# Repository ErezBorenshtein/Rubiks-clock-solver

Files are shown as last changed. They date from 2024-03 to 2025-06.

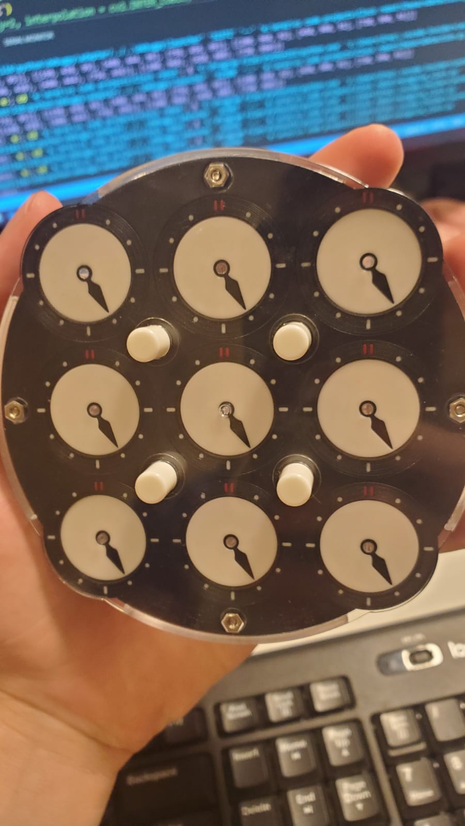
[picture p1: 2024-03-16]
Code/python_code/clock_imgs/Clock-photo3.jpg

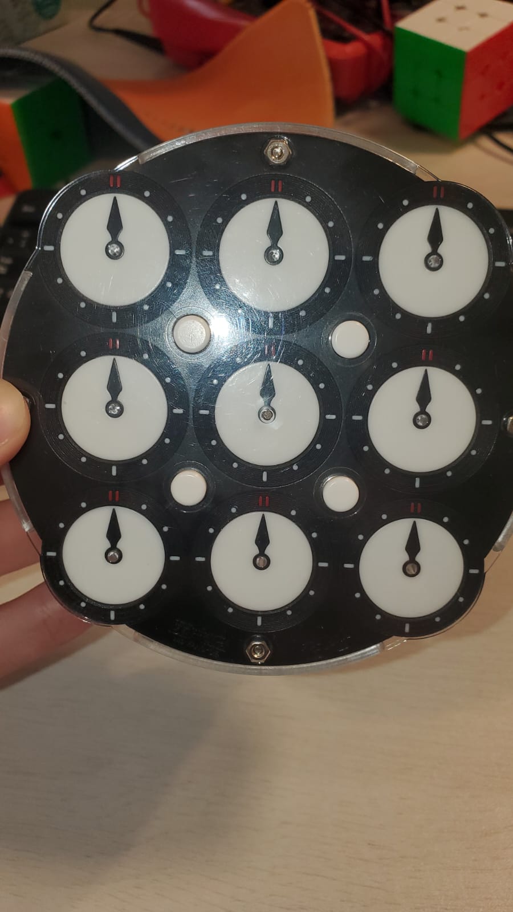
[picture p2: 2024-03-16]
Code/python_code/clock_imgs/Clock-photo.jpg

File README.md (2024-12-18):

# Rubik's Clock Solver Robot

## Overview
The robot was meticulously designed and programmed to solve the Rubik's Clock puzzle in record time, showcasing precision engineering and advanced programming techniques.

## Features
- **Precision Mechanisms:** Powered by Nema 17 Bipolar 0.9° stepper motors for high accuracy.
- **Solving Algorithm:** Optimized algorithm for determining the quickest solution.
- **Hardware Components:**
  - Arduino Mega for robot control
  - Teensy 4.1 for LED display management
  - JF-0530B solenoids for precise movement
  - 4TB-8800TB motor driver
  - 32x64 LED display for status updates
- **Autonomous Operation:** Fully automated solving process from start to finish, not including clock's recognition.

## Hardware Setup
1. **Motors:** Connect the Nema 17 stepper motors to the motor driver.
2. **Solenoids:** Interface the JF-0530B solenoids with the Arduino Mega.
3. **Microcontrollers:**
   - Use the Arduino Mega as the main controller for the robot.
   - Use the Teensy 4.1 to control the 32x64 LED screen.
4. **LED Screen:** Mount the screen to display solving steps and timings.
5. **Power Supply:** Ensure stable power for all components.

### Dependencies
- [Arduino IDE](https://www.arduino.cc/en/software)
- [Teensyduino](https://www.pjrc.com/teensy/teensyduino.html)

### Installation
1. Clone the repository:
   ```bash
   git clone https://https://github.com/ErezBorenshtein/Rubiks-clock-solver.git
   ```
2. Open the Arduino IDE and load the provided `.ino` files for the Arduino Mega and Teensy 4.1.
3. Install the required libraries via the Arduino Library Manager, and add the Teensy board from the Board Manager.
4. Upload the respective code to the Arduino Mega and Teensy 4.1.
5. Install the necessary libraries for the clock recognition system.

### Execution
1. Power on the robot.
2. Place the scrambled Rubik's Clock on the designated platform.
3. Press the start button to initiate the solving process.
4. Monitor the progress on the LED display.

## Challenges
- Designing precise mechanisms to manipulate the clock's dials and clocks.
- Synchronizing multiple components, including motors, solenoids, and the LED display.
- Creating full simulation of the clock using to test the algorithm. 
- Creating full 3D model of the robot to test the mechanism. 

## License
This project is open-sourced under the MIT License. Feel free to use, modify, and distribute as per the terms of the license.

## Acknowledgments
- The speedcubing community for inspiration.
- Open-source libraries and tools that made this project possible.
- Nyanyan-Maker for the inspiration and for suggesting motors and drivers. [youtube](https://www.youtube.com/watch?v=jc3e5xadDao)

## Contact
For questions or collaborations, reach out via [email](erez.borenshtein@gmail.com).

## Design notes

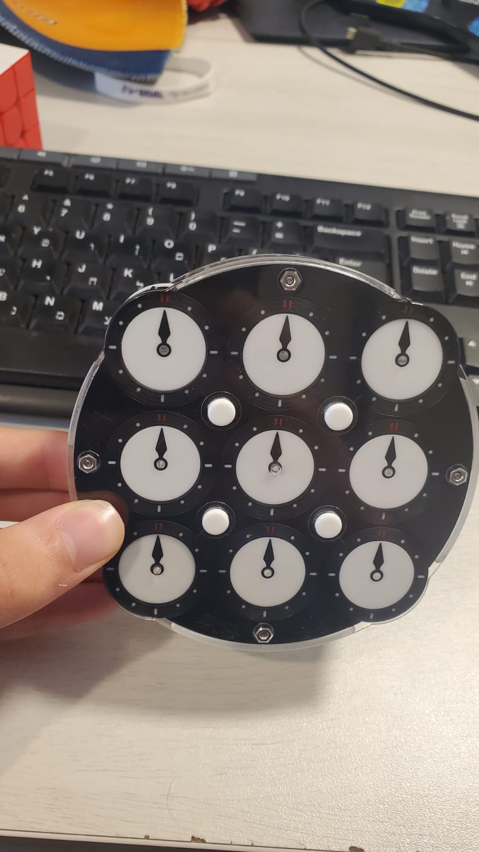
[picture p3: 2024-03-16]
Code/python_code/clock_imgs/Clock-photo2.jpg

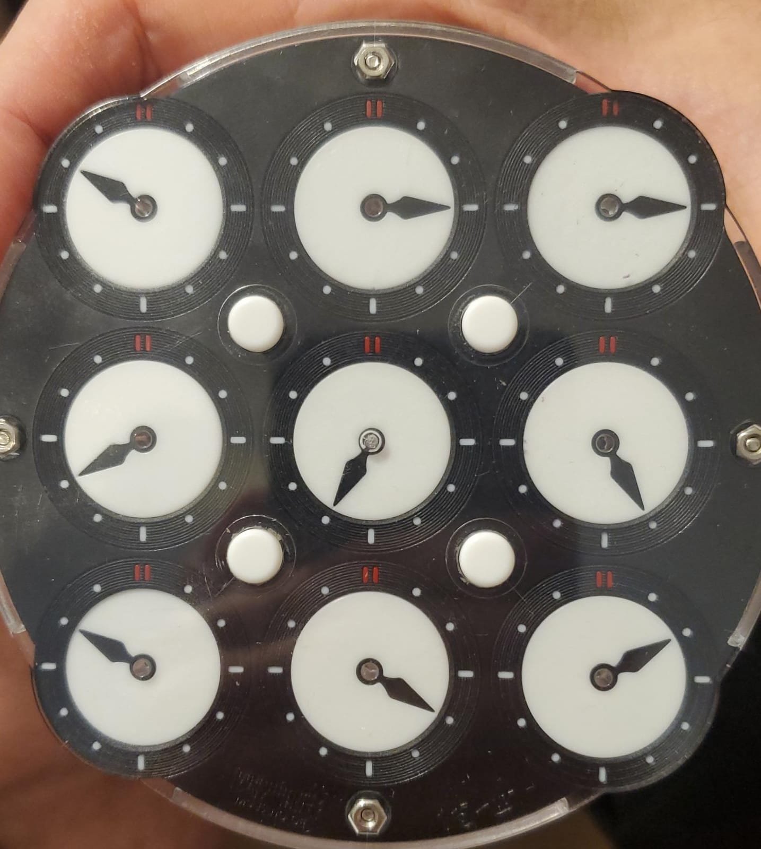
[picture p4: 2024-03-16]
Code/python_code/clock_imgs/Clock-photo6.jpg

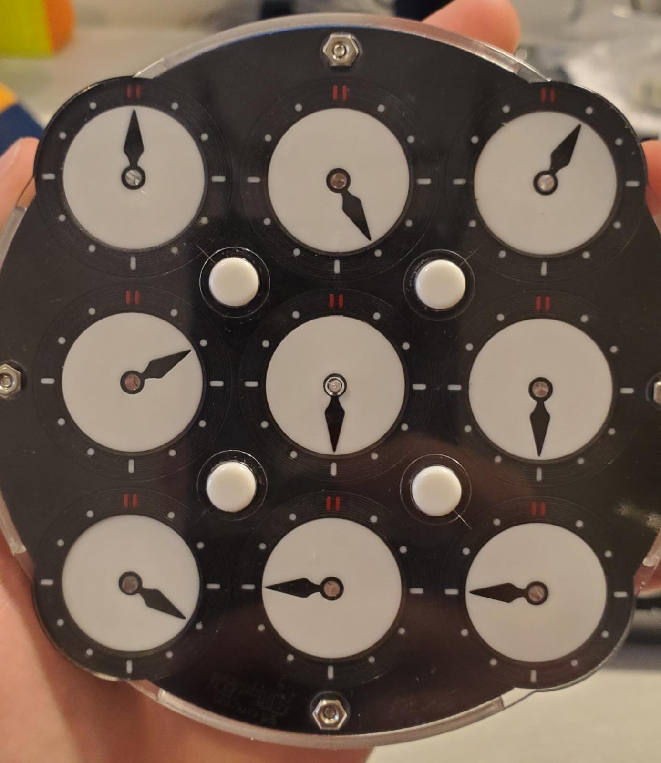
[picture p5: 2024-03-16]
Code/python_code/clock_imgs/Clock-photo5.jpg

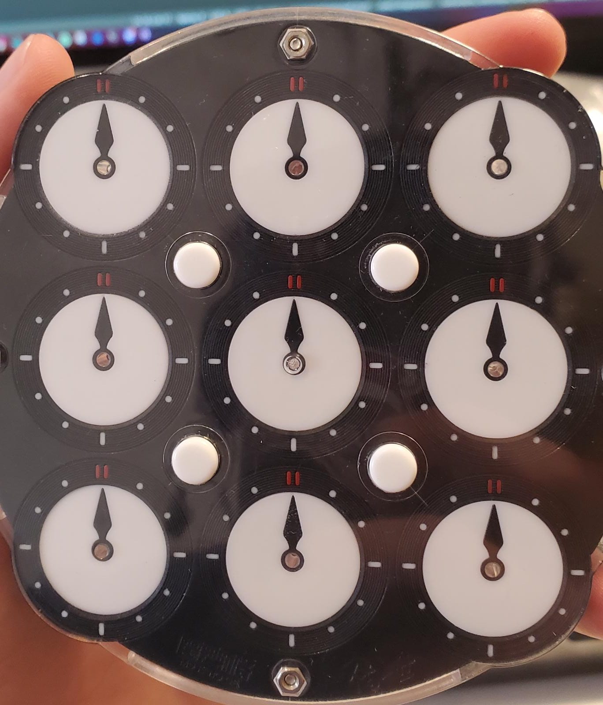
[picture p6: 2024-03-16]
Code/python_code/clock_imgs/Clock-photo4.jpg

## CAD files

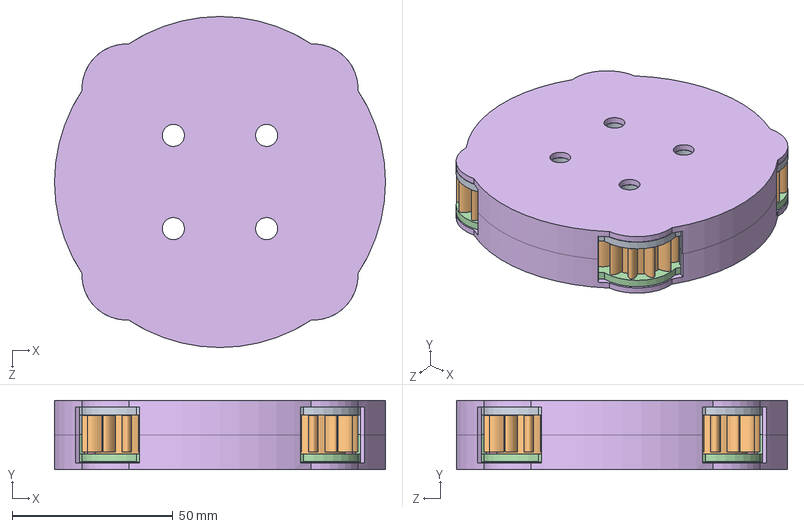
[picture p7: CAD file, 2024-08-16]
Solid parts/clock_model/full clock.SLDASM
103.0 x 21.5 x 103.0 mm
cover_white
corner_wheel x 4
black_edge x 5
cover_black
white_edge x 5
transparent_layer x 2

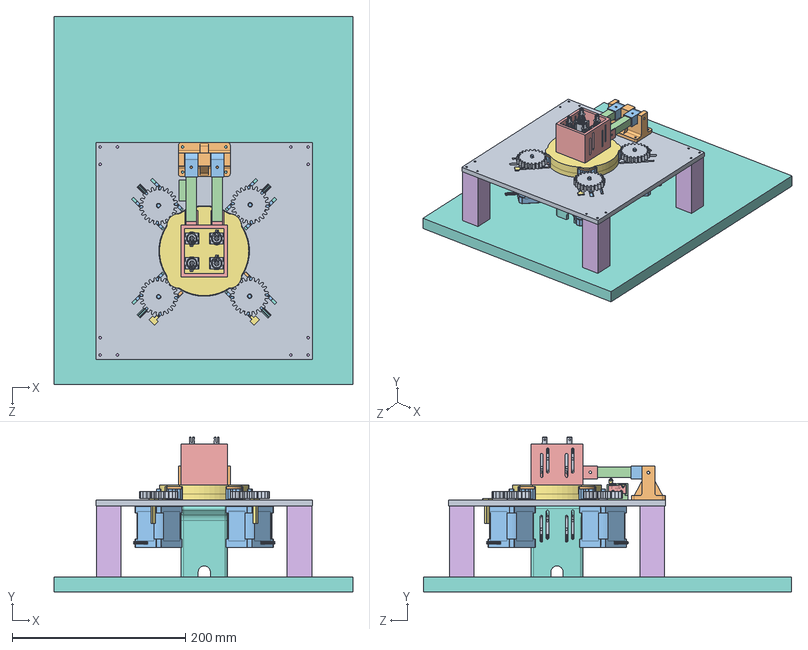
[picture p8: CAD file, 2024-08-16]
Solid parts/full machine.SLDASM
345.0 x 178.6 x 425.0 mm
Base
cover_white
corner_wheel x 4
black_edge x 5
cover_black
white_edge x 5
transparent_layer x 2
solenoid_mount.SLDASM
User Library-JF-0520B x 8
bridge base
brige_part_2 x 2
stick x 2
pushers base top
legs x 4
T holder x 2
machine_base
Stepper wheel large x 4
inner_spacer x 2
17HM19-1684S.step x 4
limit_switch_mount
Switch_Button
Link
Wheel shaft
Wheel

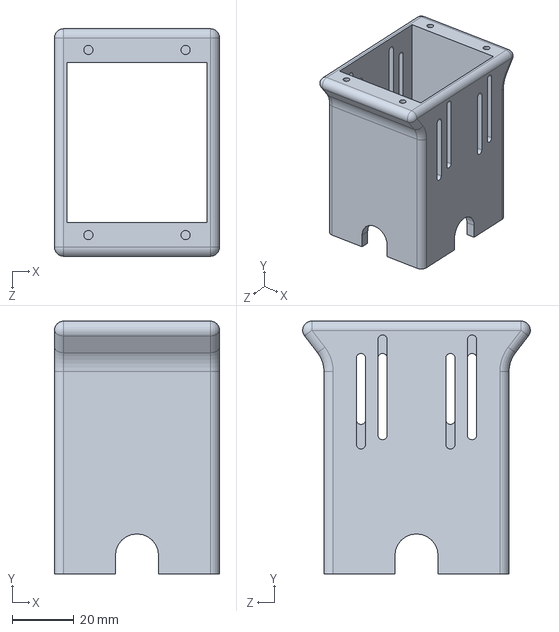
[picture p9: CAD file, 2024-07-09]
Solid parts/solenoid_mount.SLDASM.SLDPRT
53.5 x 82.0 x 73.8 mm

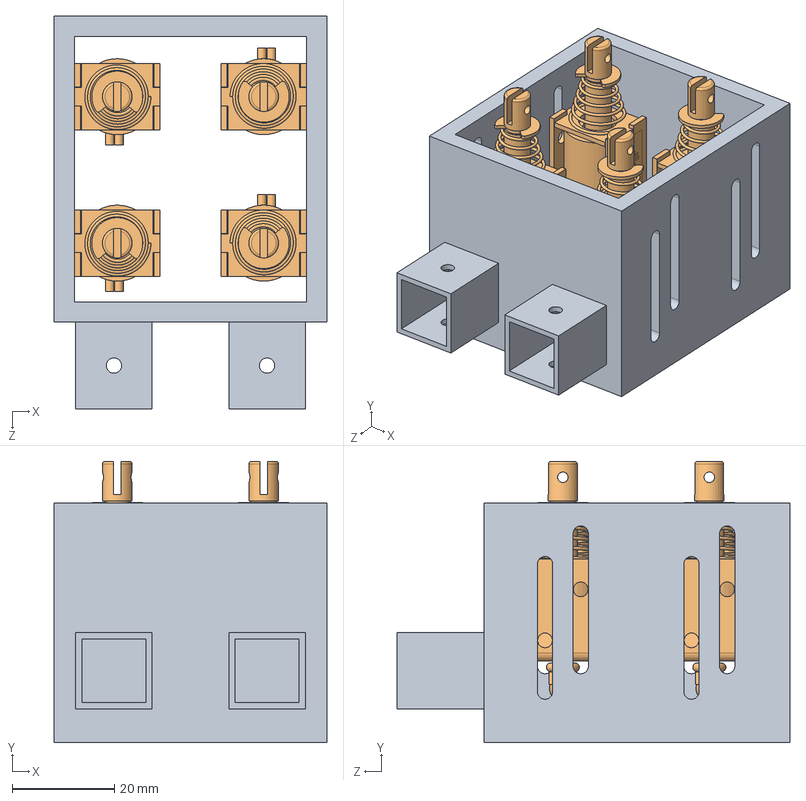
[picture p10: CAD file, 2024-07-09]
Solid parts/pusher_base_top.SLDASM
53.5 x 55.1 x 77.0 mm
pushers base top
User Library-JF-0520B x 4

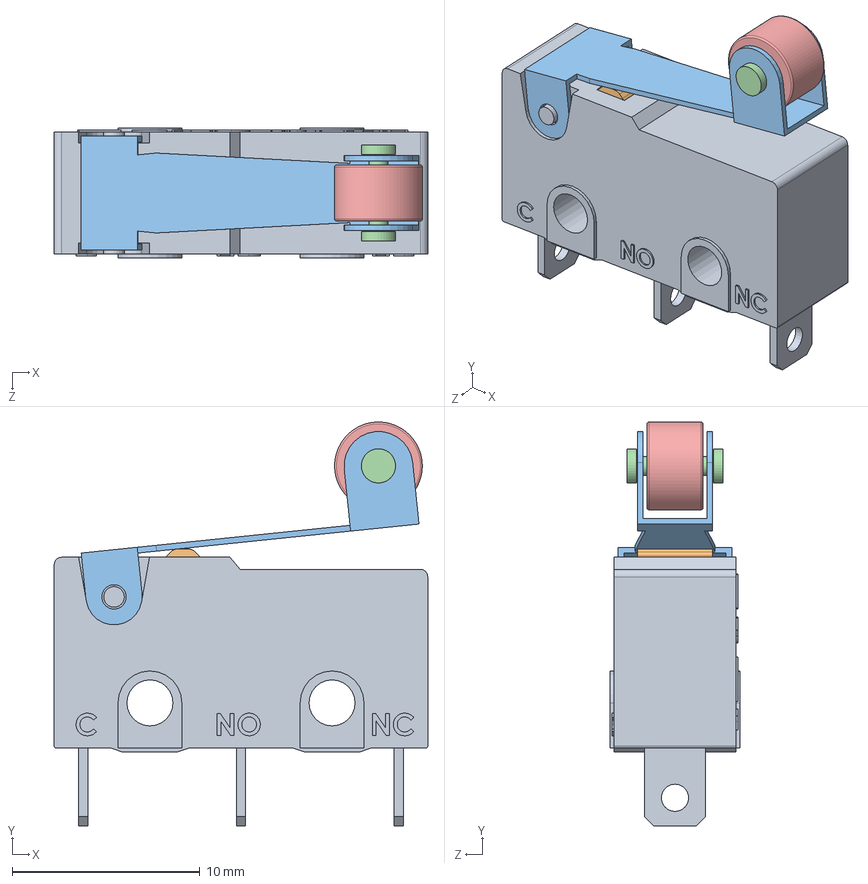
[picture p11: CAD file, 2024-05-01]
Solid parts/limt switch/Limit Switch.SLDASM
19.9 x 21.5 x 6.90 mm
Switch_Button
Link
Wheel shaft
Wheel

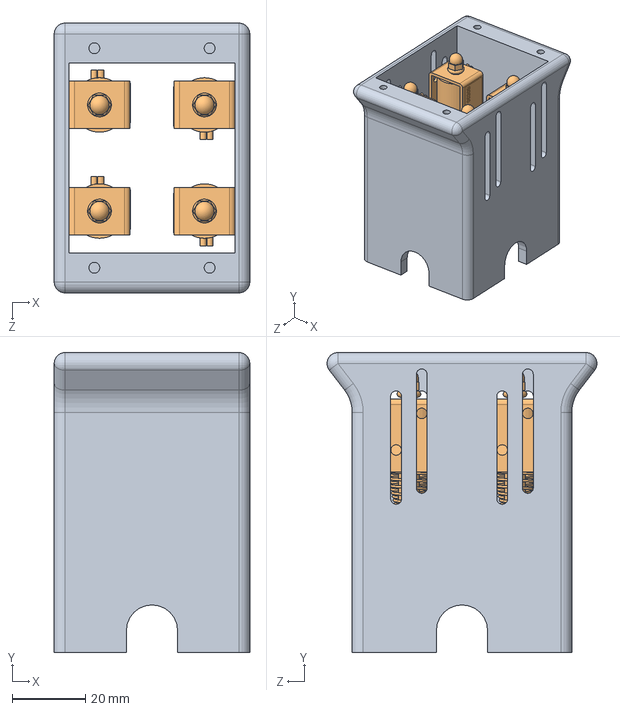
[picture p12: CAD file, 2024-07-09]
Solid parts/pusher_base.SLDASM
53.5 x 82.0 x 73.8 mm
solenoid_mount.SLDASM
User Library-JF-0520B x 4

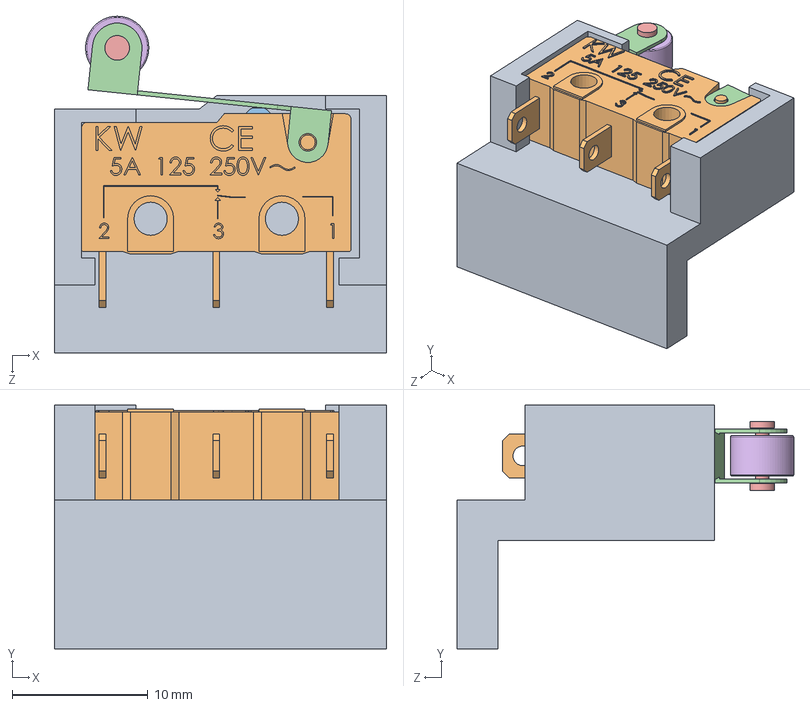
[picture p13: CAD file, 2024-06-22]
Solid parts/limit_mount_asam.SLDASM
24.5 x 18.0 x 24.8 mm
limit_switch_mount
Switch_Button
Link
Wheel shaft
Wheel

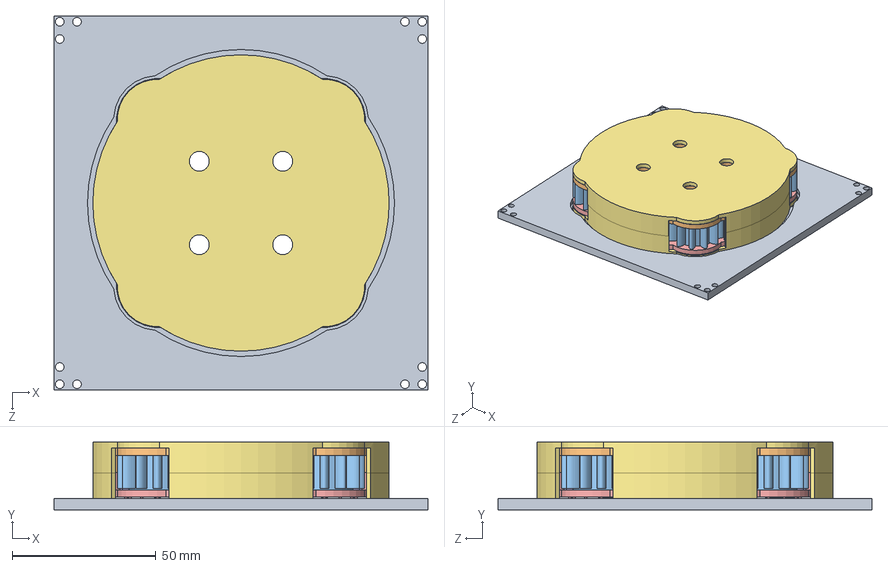
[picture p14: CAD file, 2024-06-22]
Solid parts/Camera_base_assembly.SLDASM
130.0 x 23.5 x 130.0 mm
Camera_base
cover_white
corner_wheel x 4
black_edge x 5
cover_black
white_edge x 5
transparent_layer x 2

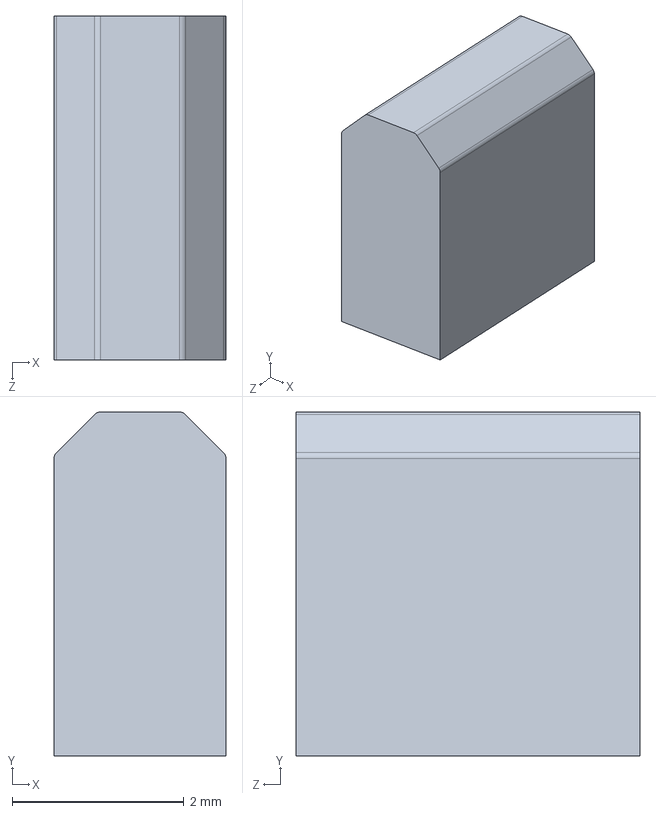
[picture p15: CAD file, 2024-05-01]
Solid parts/limt switch/Switch_Button.SLDPRT
2.00 x 4.00 x 4.00 mm

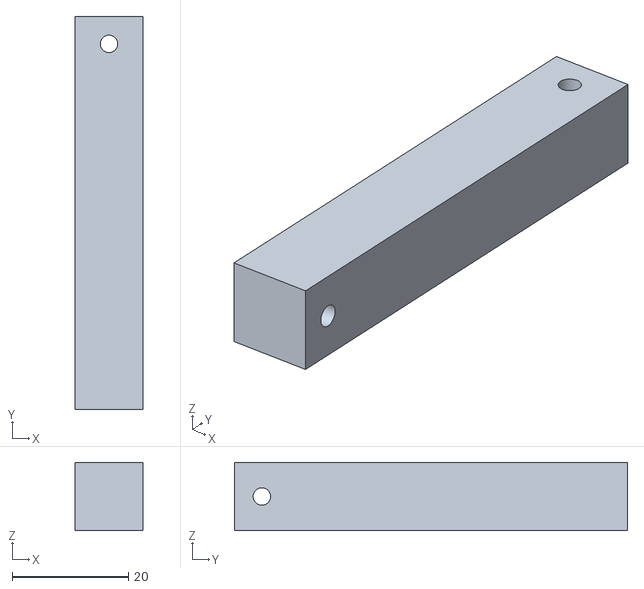
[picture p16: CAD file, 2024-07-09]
Stl parts/Bridge_stick.STL
11.7 x 67.5 x 11.7

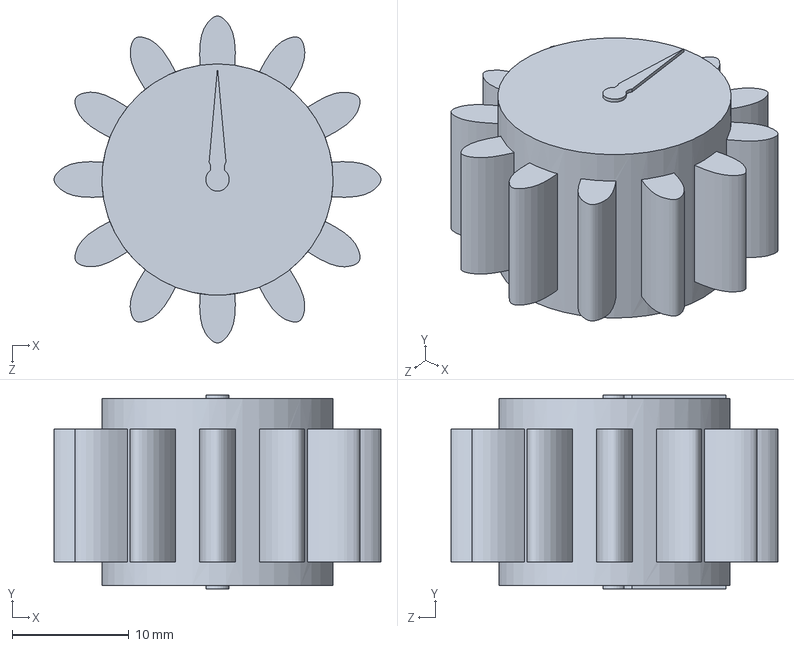
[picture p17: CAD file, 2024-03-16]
Solid parts/clock_model/corner_wheel.SLDPRT
28.0 x 16.6 x 28.0 mm

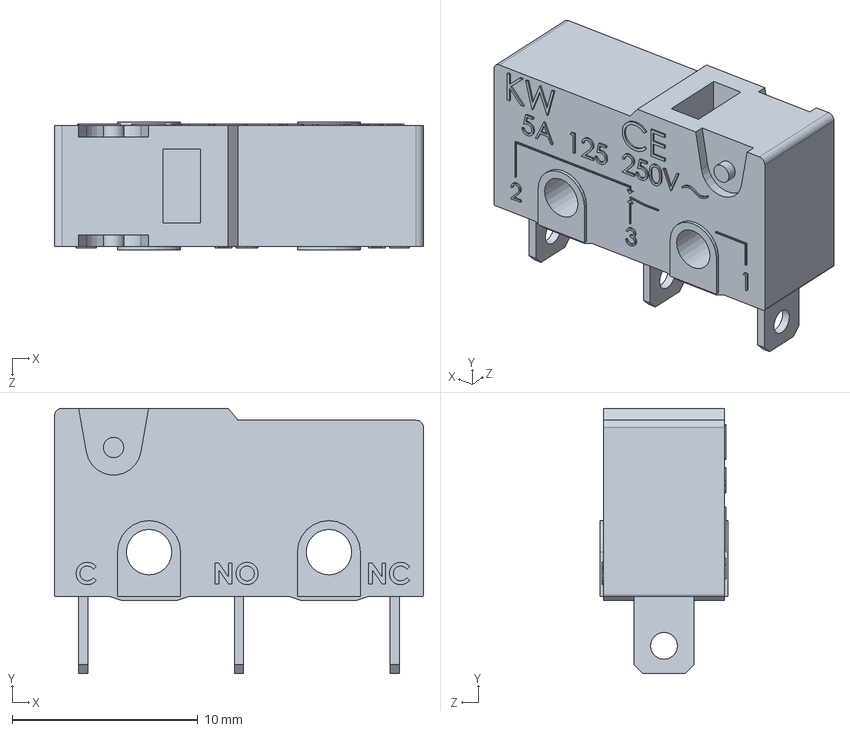
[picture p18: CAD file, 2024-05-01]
Solid parts/limt switch/Body.SLDPRT
19.9 x 14.3 x 6.90 mm

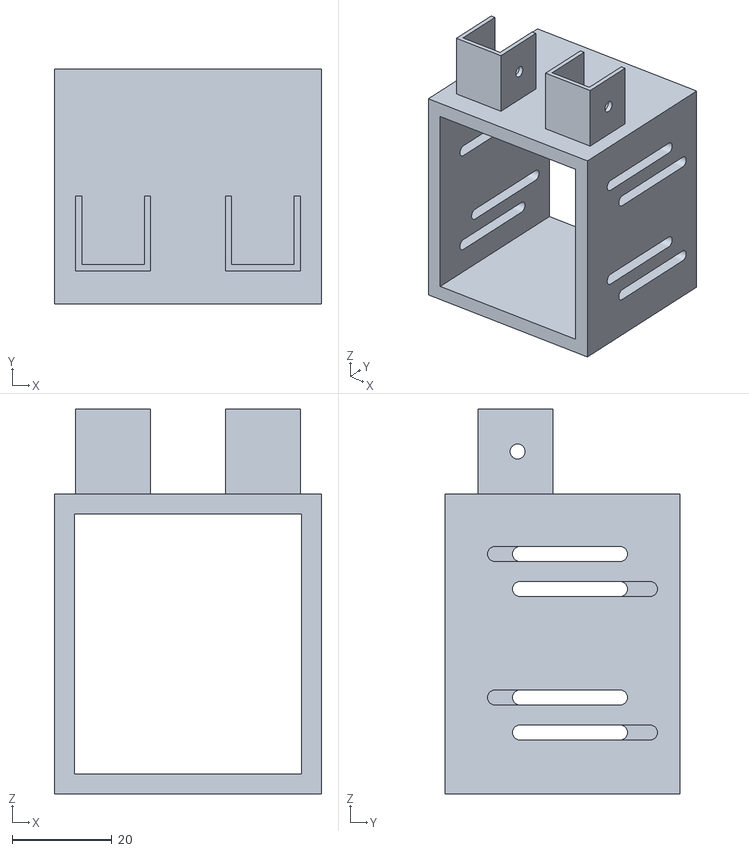
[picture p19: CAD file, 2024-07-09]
Stl parts/Solenoid_mount_top.STL
53.5 x 47.0 x 77.0

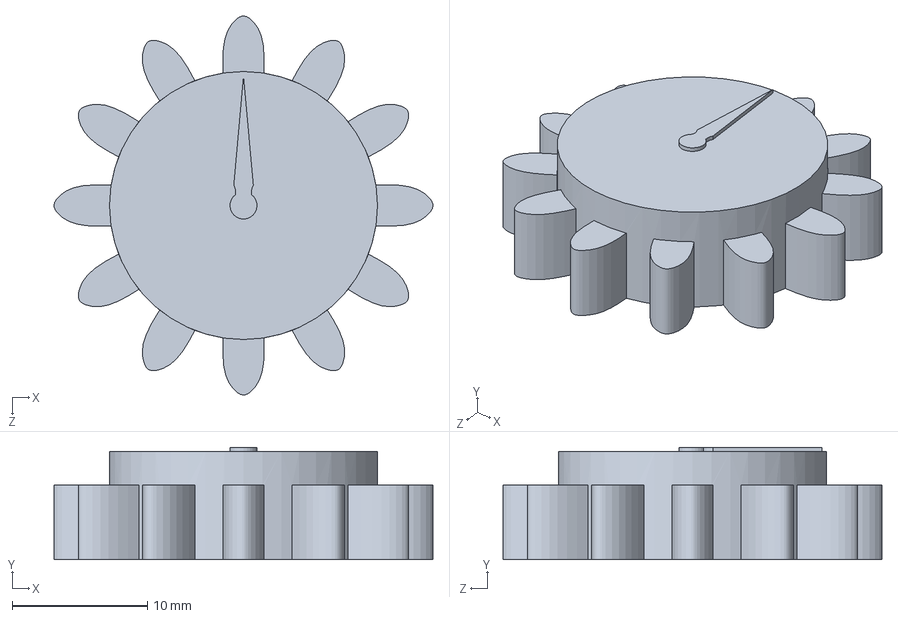
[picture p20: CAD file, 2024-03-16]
Solid parts/clock_model/white_edge.SLDPRT
28.0 x 8.30 x 28.0 mm

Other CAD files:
Solid parts/clock_model/full pin.SLDASM
Solid parts/limt switch/Wheel shaft.SLDPRT
Solid parts/stick.SLDPRT
Stl parts/led_matrix_case.STL
Solid parts/17HM19-1684S.STEP
Solid parts/Base.SLDPRT
Solid parts/Camera_base.SLDPRT
Solid parts/Camera_base_2.SLDPRT
Solid parts/Stepper wheel large.SLDPRT
Solid parts/Stepper wheel.SLDPRT
Solid parts/T holder.SLDPRT
Solid parts/User Library-JF-0520B.sldprt
Solid parts/bridge base.SLDPRT
Solid parts/brige_part_2.SLDPRT
Solid parts/clock_model/black_edge.SLDPRT
Solid parts/clock_model/cover_black.SLDPRT
Solid parts/clock_model/cover_white.SLDPRT
Solid parts/clock_model/edge_black.SLDPRT
Solid parts/clock_model/half_pin.SLDPRT
Solid parts/clock_model/transparent_layer.SLDPRT
Solid parts/inner_spacer.SLDPRT
Solid parts/led_matrix_case.SLDPRT
Solid parts/legs.SLDPRT
Solid parts/limit_switch_mount.SLDPRT
Solid parts/limt switch/Link.SLDPRT
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

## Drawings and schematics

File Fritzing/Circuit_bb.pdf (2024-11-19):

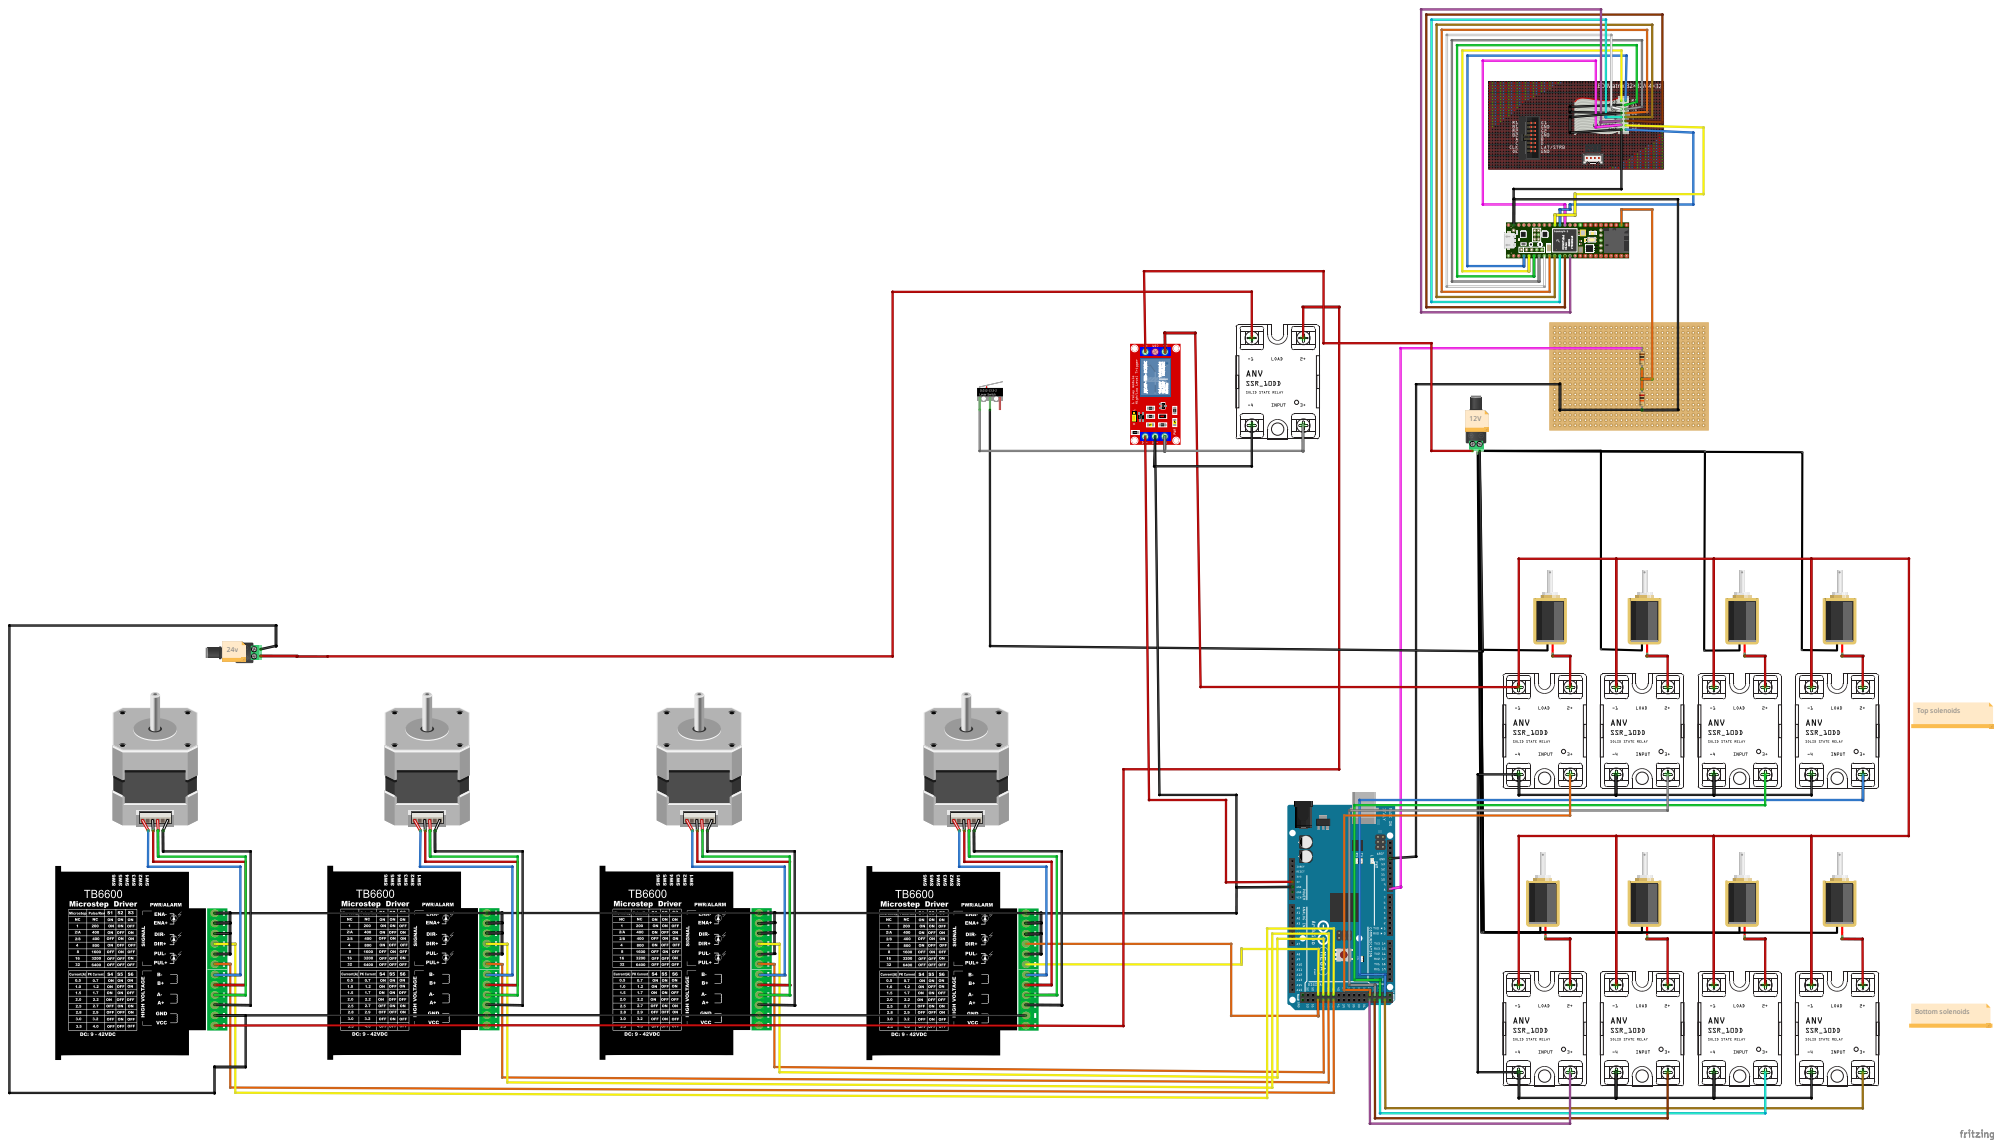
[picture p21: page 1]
Bottom solenoids; Top solenoids

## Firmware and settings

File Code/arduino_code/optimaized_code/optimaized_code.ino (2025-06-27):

#include <Bounce2.h>

#define LIMIT_PIN 18
#define MOTOR_ENABLE_PIN 19


//some delay time after the wheels completed roatation. tests show that some time is needed (around 5ms)
//#define ROTATION_DELAY 35  //!for testing without pins
#define ROTATION_DELAY 5  //full operation time


//how much time the dolenoid needs current in order to successfully move the pin. tests show that 35ms is the minimal time
#define PUSHER_DELAY 39 //for full operation time
//#define PUSHER_DELAY 42  //for testing - relaxed mode
//works well - 40

//#define TIMER_PIN 14  //no need to define pin for timer, as it is handled by Serial3

//motors rotation speed. 700 is the optimized
#define ROATATION_SPEED 640
//works well - 500


volatile const int stepPul[4] = { 48, 46, 44, 42 };
volatile const int stepDir[4] = { 49, 47, 45, 43 };

Bounce debouncer = Bounce();

void disablePins() {
  for (int i = 0; i < 4; i++) {
    digitalWrite(stepPul[i], LOW);
    digitalWrite(stepDir[i], LOW);
  }
}

class Solenoids {
public:

  int solenoidTUR;
  int solenoidTDR;
  int solenoidTDL;
  int solenoidTUL;

  //solenoids on the bottom side
  int solenoidBUR;
  int solenoidBDR;
  int solenoidBDL;
  int solenoidBUL;

  Solenoids() {
    //solenoids on the top side
    solenoidTUR = 22;
    solenoidTDR = 24;
    solenoidTDL = 26;
    solenoidTUL = 28;

    //solenoids on the bottom side
    solenoidBUR = 23;
    solenoidBDR = 25;
    solenoidBDL = 27;
    solenoidBUL = 29;

    for (int i = solenoidTUR; i <= solenoidBUL; i++) {
      pinMode(i, OUTPUT);
    }
  }


  void push(int pin, int side) {
    int actualPin = pin + side;  // Top or bottom solenoids
    digitalWrite(actualPin, HIGH);
    //String pins_names[] = {"UR-D","UR-U","DR-D","DR-U","DL-D","DL-U","UL-D","UL-U"};
    //Serial.println("pushed: "+pins_names[actualPin-22]);
  }

  void reset() {
    set(1, 1, 1, 1);
  }


  void set(int stateUR, int stateDR, int stateDL, int stateUL) {
    push(solenoidTUR, stateUR);
    push(solenoidTDR, stateDR);
    push(solenoidTDL, stateDL);
    push(solenoidTUL, stateUL);
    //Serial.println("setting solenoids");
    delay(PUSHER_DELAY);  //the lowest time that the solenoids can be on
    for (int i = solenoidTUR; i <= solenoidBUL; i++) {
      digitalWrite(i, LOW);
    }
    delay(5);
  }
};

class ClockSteppers {
public:
  //const int speed = 700;
  int speed = ROATATION_SPEED;
  const long turnSteps = 400 * 2;

  long currentPositions[4] = { 0, 0, 0, 0 };

  ClockSteppers() {
    for (int i = 0; i < 4; i++) {
      pinMode(stepPul[i], OUTPUT);
      pinMode(stepDir[i], OUTPUT);
    }

    disablePins();
  }

  void moveMotor(long steps[]) {

    long maxSteps = 0;
    for (int i = 0; i < 4; i++) {
      bool hl = true;
      if (steps[i] > 0) hl = false;
      digitalWrite(stepDir[i], hl);
      steps[i] = abs(steps[i]);
      steps[i] *= 2;  // pulse is defined by lowering and rising the pin so it should be doubled
      if (steps[i] > maxSteps) maxSteps = steps[i];
      //steps[i] = steps[i] * turnSteps / 360;
      //Serial.println("steps: "+String(steps[i]));
    }
    //Serial.println("maxSteps: "+String(maxSteps));

    long avgTime = 1000000 * 60 / turnSteps / speed;
    long maxTime = 375;
    long slope = 10;
    long accel = min(maxSteps, max(0, (maxTime - avgTime) / slope));
    bool motorPulse = false;
    for (int i = 0; i < maxSteps; i++) {
      motorPulse = !motorPulse;

      for (int j = 0; j < 4; j++) {
        if (i < steps[j]) {
          digitalWrite(stepPul[j], motorPulse);
        }
      }

      long delay_time = avgTime;
      if (i < accel) delay_time = maxTime - slope * i;
      //Serial.println("delay_time: "+String(delay_time));
      delayMicroseconds(delay_time);
    }
  }

  void moveTo(long toPositions[]) {
    long steps[4];
    for (int i = 0; i < 4; i++) {
      steps[i] = toPositions[i] - currentPositions[i];
      //Serial.println("steps: "+String(steps[i]));
    }

    moveMotor(steps);

    for (int i = 0; i < 4; i++) {
      currentPositions[i] = toPositions[i];
    }
  }
};


class Clock {
public:
  //const int stepsPerRotation = (400*(3.0/4))*2; // 400 is the number of steps per rotation, 3/4 is the gear ratio, 8 is the microstepping
  const float stepsPerRotation = (400 * (12.0 / 22.0)) * 2;  // 400 is the number of steps per rotation, 3/4 is the gear ratio, 8 is the microstepping
  //const int stepsPerRotation = (400*(9.9/18.15))*2; // 400 is the number of steps per rotation, 12/22 is the gear ratio, 8 is the microstepping
  //int offset[4] = {0,0,0,0}; //gear ratio offset for each wheel

  Solenoids solenoids;

  ClockSteppers clockSteppers;


  void setPins(int stateUR, int stateDR, int stateDL, int stateUL) {
    solenoids.set(stateUR, stateDR, stateDL, stateUL);
    //Serial.println("setting pins: "+String(stateUR)+String(stateDR)+String(stateDL)+String(stateUL));
  }


  void rotate(float positions_degs[4]) {
    long steps[4];
    for (int i = 0; i < 4; i++) {
      //steps[i] = (positions_degs[i]*(stepsPerRotation+offset[i])/360.0)+0.5;
      float roundFactor = positions_degs[i] > 0 ? 0.5 : -0.5;
      steps[i] = (positions_degs[i] * stepsPerRotation / 360.0) + roundFactor;
      //Serial.println("steps "+String(i)+": "+String(steps[i])+ "      degs: "+String(positions_degs[i]));
    }

    clockSteppers.moveTo(steps);
  }

  void reset() {
    solenoids.reset();
  }
};

class ClockOperator {
public:
  Clock clock;
  float wheels_states_degs[4];
  int current_pins_states[4];  //used for monitoring the state of the clock pins

  ClockOperator() {
    for (int i = 0; i < 4; i++) {
      wheels_states_degs[i] = 0.0;
    }
  }

  void rotate(String command) {
    Serial.println(command);

    //TODO: check if the command is valid
    //check if pin's states is valid for rotation
    //int moving_wheel_pin_state = (command[3]-'0' == current_pins_states[0]); //The state of the pins around the moving wheel
    //for(int i=1;i<4;i++){
    //  int expected_pin_state = moving_wheel_pin_state==(command[i+3]-'0');//The state of the current pin near the wheel

    //  if(expected_pin_state != current_pins_states[i]){
    //    Serial.println("pin state is not valid expected: "+String(expected_pin_state)+" current: " + String(current_pins_states[i]));
    //    while(true){ //Stop the program
    //      delay(10);
    //    }
    //  }
    //}

    //calculate how much each wheel need to move
    float positions_degs[4];
    for (int i = 0; i < 4; i++) {
      float hours_deg = (command[i * 2 + 2] - '0') * 360.0 / 12.0;

      if (command[i * 2 + 1] == '-') {
        hours_deg *= -1;
      }

      //Serial.println("hours_deg: "+String(hours_deg));

      positions_degs[i] = wheels_states_degs[i] + hours_deg;
      wheels_states_degs[i] = positions_degs[i];  //update the current wheel state
                                                  //Serial.println("wheel "+String(i)+": "+String(positions_degs[i]));
    }
    clock.rotate(positions_degs);
  }


  void setPins(String command) {
    current_pins_states[0] = command[1] - '0';
    current_pins_states[1] = command[2] - '0';
    current_pins_states[2] = command[3] - '0';
    current_pins_states[3] = command[4] - '0';
    clock.setPins(command[1] - '0', command[2] - '0', command[3] - '0', command[4] - '0');
  }

  bool isCommandValid(String command) {

    if (command[0] != 'r' && command[0] != 'p') {

      Serial.println("ERR6");
      Serial.println(command[0]);
      return false;
    }

    if (command.length() != 9) {
      Serial.println("ERR5");
      Serial.println(command.length());
      return false;
    }

    if (command[0] == 'r') {
      for (int i = 0; i < 4; i++) {
        if (command[i * 2 + 1] != '+' && command[i * 2 + 1] != '-') {
          //Serial.println("command[i*2+1]: "+command[i*2+1]);
          Serial.println("ERR1");
          return false;
        }
        if (command[i * 2 + 2] < '0' && command[i * 2 + 2] > '6') {
          Serial.println("ERR2");
          return false;
        }
      }
    }
    if (command[0] == 'p') {
      if (command[5] != '0' && command[6] != '0' && command[7] != '0' && command[8] != '0') {
        Serial.println("ERR3");
        return false;
      }
      for (int i = 3; i < 7; i++)
        if (command[i] > '1' && command[i] < '0') {
          Serial.println("ERR4");
          return false;
        }
    }
    return true;
  }

  void runCommand(String command) {

    //Serial.println("running command: "+command);

    if (!isCommandValid(command)) {
      Serial.println("command is not valid");
      return;
    }
    
    //Serial.println("running command:" + command);
    //delay(100);
    if (command[0] == 'r') {
      
      rotate(command);
      delay(ROTATION_DELAY);
    }

    if (command[0] == 'p') {
      setPins(command);
    }

    //delay(500);
  }

  void solve(String solution) {

    int chunkSize = 9 + 1;
    int numOfCommands = solution.length() / chunkSize;
    Serial.println("num of commands: " + String(numOfCommands));
    for (int i = 0; i < numOfCommands; i++) {
      String command = solution.substring(i * chunkSize, (i + 1) * chunkSize - 1);
      //Serial.println("command"+command);
      runCommand(command);
    }
  }


  void reset() {
    Serial.println("Resetting...");
    for (int i = 0; i < 4; i++) {
      current_pins_states[i] = 0;
    }
    clock.reset();
  }

  void checkPins() {
    setPins("p0000  ");
    delay(100);
    reset();
  }
};


ClockOperator clockOperator;
String commands = "";

void powerEnabler() {
  int mode;
 
  digitalWrite(MOTOR_ENABLE_PIN, LOW);
  do {
    mode = digitalRead(LIMIT_PIN);
  } while (mode == 1);

  //Serial.println("setting enble to high");
  digitalWrite(MOTOR_ENABLE_PIN, HIGH);
  disablePins();
}

void powerEnablerNoInterrupt() {
  int mode;
  //Serial.println("setting enble to low");
  delay(10);
  digitalWrite(MOTOR_ENABLE_PIN, LOW);
  do {
    mode = digitalRead(LIMIT_PIN);
    digitalWrite(LED_BUILTIN, mode);
    delay(3);
  } while (mode == 1);

  //Serial.println("setting enble to high");
  digitalWrite(MOTOR_ENABLE_PIN, HIGH);
  delay(10);
  disablePins();
  delay(2000);
}




void waitForLimitLow() {
  while (true) {
    debouncer.update();
    if (debouncer.read() == LOW) {
      break;  // Switch is pressed (debounced)
    }
    delay(1);  // Small delay to reduce CPU load
  }
}

//this is the setup for testing the robot
void setup2() {
  Serial.begin(115200);
  Serial3.begin(115200);
  delay(50);

  debouncer.attach(LIMIT_PIN);
  debouncer.interval(10);  // 10 ms debounce interval

  Serial3.println("reset");

  pinMode(LIMIT_PIN, INPUT_PULLUP);
  pinMode(MOTOR_ENABLE_PIN, OUTPUT);
  pinMode(LED_BUILTIN, OUTPUT);

  //pinMode(TIMER_PIN, OUTPUT);
  //digitalWrite(TIMER_PIN, LOW);
  //Serial.println("setting enable to low");
  digitalWrite(MOTOR_ENABLE_PIN, LOW);
  delay(10);

  waitForLimitLow();  // Wait until the switch is pressed
  //Serial.println("Limit switch activated!");
  debouncer.attach(255);  //detach the bounce from the pin

  attachInterrupt(digitalPinToInterrupt(LIMIT_PIN), powerEnabler, CHANGE);
  powerEnablerNoInterrupt();
  //UR1+ DR4- DL2- UL2- U3- R1+ D1- L3+ ALL5- y2 U2- R2+ D1+ L5- ALL0+
  //commands = "p01110000 r-2-2-2-2 p00110000 r-3-3-3-3 p00010000 r-3-3-3+4 p01010000 r+6+1+6+1 p01000000 r-4-5-4-4 p11000000 r-5-5+1+1 p11010000 r-2-2+1-2\n";
  //UR2+ DR4- DL5- UL1- U5- R1- D0+ L4+ ALL1+ y2 U4+ R1+ D3- L2+ ALL2-
  //commands = "p01110000 r+4-2-2-2 p00110000 r-2-2-2-2 p00010000 r-4-4-4+4 p01010000 r-3+6-3+6 p01000000 r+6-3+6+6 p11000000 r-6-6+4+4 p11010000 r+0+0-3+0\n";

  //UR1- DR0+ DL4+ UL2+ U0+ R0+ D2+ L4+ ALL6+ y2 U5- R1- D1+ L2+ ALL3+
  //commands = "p01110000 r-5-2-2-2 p00110000 r-5-5+3+3 p00010000 r-2-2-2-1 p01010000 r-4-5-4-5 p01000000 r+5+6+5+5 p11000000 r-5-5-2-2 p11010000 r-1-1+1-1\n";
  //commands = "p01110000 r-3-4-4-4 p00110000 r+0+0+0+0 p00010000 r-3-3-3+0 p01010000 r+3-5+3-5 p01000000 r+2+2+2+2 p11000000 r+0+0+0+0 p11010000 r-2-2+2-2\n";

  //clockOperator.reset();  //needed only after optimizing pin settings
  delay(1500);
}


//this is the full operational
void setup() {
  Serial.begin(115200);
  Serial3.begin(115200);

  delay(50);

  Serial3.println("reset");
  //Serial.println("-------------------------------------------------------------------");
  pinMode(LIMIT_PIN, INPUT_PULLUP);
  pinMode(MOTOR_ENABLE_PIN, OUTPUT);
  
  delay(10);
  Serial.println ("Ready to start, close the robot");
  delay (20);
  attachInterrupt(digitalPinToInterrupt(LIMIT_PIN), powerEnabler, CHANGE);
  powerEnablerNoInterrupt();
  
  Serial.println("waiting for serial");
  // Wait for serial port to open
  while (!Serial) {
    delay(10);  // Wait for serial port to connect
  }

  Serial.println("ready");  //!important! part of the protocol
  delay (50);




  delay(50);
  Serial3.println("reset");
  commands = "";
  char incomingChar;
  while (true) {
    if (Serial.available()) {
      if (commands == "")
        Serial.println ("first char recieved");
      incomingChar = Serial.read();
      if (incomingChar == '\n') {
        break;  // message complete
      }
      commands += incomingChar;
      Serial.print(incomingChar);
      
    }
  }
  Serial.println("");

  // Print the received string
  Serial.println("Received: " + commands);
  Serial.println (commands.length());
  //commands = "p0111   r+01000 r-20111 p0011   r+01100 r+00011 p0001   r-10001 r+11110 p0101   r+20101 r-21010 p0100   r-10100 r+11011 p1100   r+01100 r+00011 p1101   r-21101 r+00010\n";

  Serial.println("end of read");
  //clockOperator.reset();  //needed only after optimizing pin settings

  delay(1000);
}


//this is the real setup function that is used in the loop
void loop() {
  //Serial.println((String)"mil 0: "+(String)millis());
  Serial.println("waiting for serial");
  if (Serial.available()) {
    Serial.println("serial is available");
    unsigned long start_time = millis();
    Serial3.println("start");
    Serial.println("------start");
    clockOperator.solve(commands);

    Serial3.println("stop");
    Serial.println("done");

    Serial.println("total time: " + String(millis() - start_time));
    clockOperator.reset();
    delay(1000000);
    //}
  }
  delay(3);
}


void test_motor_rotation() {

  clockOperator.runCommand("p11110000");
  clockOperator.runCommand("r+1+1+1+1");
  clockOperator.runCommand("r+3+3+3+3");
  clockOperator.runCommand("r-6-6-6-6");

  clockOperator.runCommand("p00010000");
  clockOperator.runCommand("r-3-3-3+6");
  clockOperator.runCommand("r+4+4+4-2");
  clockOperator.runCommand("r+4+4+4-2");
  clockOperator.runCommand("r-4-4-4+2");
  clockOperator.runCommand("r-1-1-1+3");

  clockOperator.runCommand("p01010000");
  clockOperator.runCommand("r-1+3-1+3");
  clockOperator.runCommand("r+6-3+6-3");
  clockOperator.runCommand("r+6-1+6-1");
  clockOperator.runCommand("r+1-1+1-1");
  clockOperator.runCommand("r+6-6+6-6");

  clockOperator.runCommand("p01110000");
  clockOperator.runCommand("r+1-1-1-1");
  clockOperator.runCommand("r+6-6-6-6");
  clockOperator.runCommand("r-6+6+6+6");
  clockOperator.runCommand("r-1-6-6-6");
  clockOperator.runCommand("r-3-5-5-5");

  clockOperator.runCommand("p11110000");
  clockOperator.runCommand("r-5-5-5-5");
  clockOperator.runCommand("r+1+1+1+1");
  clockOperator.runCommand("r-2-2-2-2");
  clockOperator.runCommand("r+6+6+6+6");


  clockOperator.runCommand("p11110000");
}

void run_command_with_delay(String command) {
  //Serial.println("running command:" + command);
  clockOperator.runCommand(command);
  delay(1000);
}

void test_pins() {
  Serial.println("testing pins");
  run_command_with_delay("p00000000");
  run_command_with_delay("p10000000");
  run_command_with_delay("p01000000");
  run_command_with_delay("p00100000");
  run_command_with_delay("p00010000");
  run_command_with_delay("p11110000");
  run_command_with_delay("p11100000");
  run_command_with_delay("p11010000");
  run_command_with_delay("p10110000");
  run_command_with_delay("p01110000");
  delay(2000000);
  run_command_with_delay("p00010000");
  run_command_with_delay("p00100000");
  run_command_with_delay("p00110000");
  run_command_with_delay("p01000000");
  run_command_with_delay("p01010000");
  run_command_with_delay("p01100000");
  run_command_with_delay("p01110000");
  run_command_with_delay("p10000000");
  run_command_with_delay("p10010000");
  run_command_with_delay("p10100000");
  run_command_with_delay("p10110000");
  run_command_with_delay("p11000000");
  run_command_with_delay("p11010000");
  run_command_with_delay("p11110000");
  run_command_with_delay("p00000000");
  run_command_with_delay("p11110000");
  run_command_with_delay("p10000000");
}

void loop2() {

  //test_motor_rotation();
  test_pins();
  delay(10000000);
}

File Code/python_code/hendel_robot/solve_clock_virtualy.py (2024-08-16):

import numpy as np
class Clock:
    def __init__(self):
        self.clock_pins = [0, 0, 0, 0] # 0 for down and 1 for up 
        self.clock = [0] * 18 # all the clocks are in the 12 o'clock position
        self.PUR, self.PDR, self.PDL, self.PUL = 0, 1, 2, 3 # pins numbers
        self.UL, self.U, self.UR, self.L, self.C, self.R, self.DL, self.D, self.DR = 0, 1, 2, 3, 4, 5, 6, 7, 8 # wheel numbers
        self.FRONT, self.BACK = 0, 9 # for the rotate function
        
        self.num_to_wheel = {
            2: "UR",
            8: "DR",
            6: "DL",
            0: "UL",
            1: "U",
            5: "R",
            7: "D",
            3: "L",
            4: "C"
        }

        self.wheel_to_num = {
            "UR": 2,
            "DR": 8,
            "DL": 6,
            "UL": 0,
            "U": 1,
            "R": 5,
            "D": 7,
            "L": 3,
            "C": 4
        }

        self.pin_mapping = {
            #wheel to pin
            "UR": (self.PUR, None),
            "DR": (self.PDR, None),
            "DL": (self.PDL, None),
            "UL": (self.PUL, None),
            "R": (self.PUR, self.PDR),
            "D": (self.PDR, self.PDL),
            "L": (self.PDL, self.PUL),
            "U": (self.PUR, self.PUL),
            "ALL": (self.PUR, self.PDR, self.PDL, self.PUL)
        }

        self.pin_num_mapping = {
            #for the front side
            self.UR: (self.PUR, None),
            self.DR: (self.PDR, None),
            self.DL: (self.PDL, None),
            self.UL: (self.PUL, None),
            self.R: (self.PUR, self.PDR),
            self.D: (self.PDR, self.PDL),
            self.L: (self.PDL, self.PUL),
            self.U: (self.PUR, self.PUL),
            #for the back side
            self.UR+9:(self.PUL, None),
            self.DR+9:(self.PDL, None),
            self.DL+9:(self.PDR, None),
            self.UL+9:(self.PUR, None),
        }

        self.wheel_mapping_str = {
            #Name to number
            "UR": self.UR,
            "DR": self.DR,
            "DL": self.DL,
            "UL": self.UL,
            "R": self.R,
            "D": self.D,
            "L": self.L,
            "U": self.U,
        }

        self.pin_mapping_reversed = {
            #pin to wheel(numbers)
            self.PUR: self.UR,
            self.PDR: self.DR,
            self.PDL: self.DL,
            self.PUL: self.UL
        }

        self.wheels_around_pin = {
            #wheels around the pin
            self.PUR: (self.UR, self.U, self.R, self.C),
            self.PDR: (self.DR, self.D, self.C, self.R),
            self.PDL: (self.DL, self.L, self.C, self.D),
            self.PUL: (self.UL, self.U, self.C, self.L)
        }


        self.wheel_mapping_rotated = {
            #clocks after y2 rotation
            "UR": "UL",
            "DR": "DL",
            "DL": "DR",
            "UL": "UR",
            "R": "L",
            "L": "R",
            "D": "U",
            "U": "D",
            "ALL": "ALL",
            "C":"C"
        }

        self.pin_side_to_wheel = {
            #what wheel to rotate for each set of pins
            "U": "UR",
            "R": "UR",
            "D": "DR",
            "L": "DL",
            "UR": "UR",
            "DR": "DR",
            "DL": "DL",
            "UL": "UL",
            "ALL": "UR",
            "ALL_BUT_0": "UL",
            "ALL_BUT_1": "UR",
            "ALL_BUT_2": "DR",
            "ALL_BUT_3": "DL",
            "UR_AND_DL": "UR",
            "DL_AND_UR": "UR",
            "UL_AND_DR": "UL",
            "DR_AND_UL": "UL",
        }

        self.pin_side_to_wheel_after_rotation = {
            #what wheel to rotate for each set of pins after y2 rotation
            "U": "DR",
            "R": "UR",
            "D": "UR",
            "L": "DL",
            "ALL": "UR",
            "UL": "UR",
            "UR": "UL",
            "DR": "DL",
            "DL": "DR",
        }

    def set_clock(self, clock):
        #set the clock to a specific configuration(if the state is valid)
        for i in [(0,11),(2,9),(6,17),(8,15)]:
            if clock[i[0]] != (12-clock[i[1]])%12:
                return False
            else:
                self.clock = clock
                return True

    def reset(self):
        # Reset the clock to its initial state
        self.clock_pins = [0, 0, 0, 0]
        self.clock = [0] * 18

    def is_solved(self):
        # Check if the clock is in a solved state
        return self.clock == [0] * 18

    def flip_pins(self):
        # Flip the pins after y2 rotaqtion
        return [1 if pin == 0 else 0 for pin in reversed(self.clock_pins)]

    def print(self):
        for i in range(len(self.clock)):
            print(self.clock[i], end=" ")
            if (i + 1) % 3 == 0 and (i + 1) % 9 != 0:
                print("\n", end="")
            elif (i + 1) % 9 == 0 and i + 1 != len(self.clock):
                print("\nBack\n", end="")
        print("\n")

    def rotate_wheel(self, wheel, num_of_rot, is_rotated):
        #simulates the rotation of the wheel on the clock

        #print("\nRotated", wheel, num_of_rot, "times","is_rotated=",is_rotated,"\n")
    
        if is_rotated == True:
            wheel =  self.pin_side_to_wheel_after_rotation[wheel] #filp the wheel if the move is after a y2 rotation
        else:
            wheel = self.pin_side_to_wheel[wheel]

        #rotates the wheel from the front side and returns the wheels that were rotated
        wheels_side_1 = self.rotate_internal(wheel, num_of_rot, self.FRONT, self.clock_pins) 

        #rotates the wheel from the back side and returns the wheels that were rotated
        wheels_side_2 =self.rotate_internal(self.wheel_mapping_rotated[wheel], -num_of_rot, self.BACK, self.flip_pins())

        #add the wheels that were rotated to the final movement
        if len(wheels_side_1) == 0: #for each move just one side is rotated, if this side is the back we'll conv
            wheels_side_1 = wheels_side_2
            wheels_side_2 = []
            i=0
            for wheel in wheels_side_1:
                if wheel in [0,2,6,8,9,11,15,17]: #the wheels that are in the corners of the clock
                    wheels_side_2.append(wheel)
            wheels_side_1 = wheels_side_2
            i=0     
            for wheel in wheels_side_1:
                wheels_side_1[i] =self.pin_mapping_reversed[self.pin_num_mapping[wheel][0]] #convert the wheels to the pins
                i+=1

        final_movement = []
        for i in range(len(wheels_side_1)):
            if len(self.num_to_wheel[wheels_side_1[i]]) != 1: #if the wheel is a corner wheel
                final_movement.append(self.num_to_wheel[wheels_side_1[i]]) #add the wheel to the final movement
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

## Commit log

2024-03-17 changed color
    [full machine.SLDASM]
2024-04-21 Updated STLs and SLDPARTs added LICENSE and update .gitignore
    [Base.STL, Bridge_base.STL, Bridge_stick.STL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]
2024-05-01 chore: Update VSCode settings and Arduino configuration files added 3d parts
    [Body.SLDPRT, Limit Switch.SLDASM, Link.SLDPRT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]
2024-05-03 added the ability to use Arduino from vs code(not for every system)
2024-06-14 chore: Update .gitignore to ignore temporary SolidWorks files
    [Solenoid_mount_bottom.STL, full machine.SLDASM, legs.SLDPRT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]
2024-06-22 chore: Update Arduino configuration and VSCode settings, add 3D parts
    [17HM19-1684S.STEP, 42 step motor-38mm (1).STEP, Camera_base.SLDPRT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]
2024-06-29 First working prototype
2024-07-01 chore: Optimize Arduino code and update clock solving algorithm
2024-07-09 Optimize Arduino code and update clock solving algorithm
    [Bridge_stick.STL, Solenoid_mount_bottom.STL, Solenoid_mount_top.STL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]
2024-08-16 Added fritzing schematic
    [Circuit.fzz, full clock.SLDASM, full machine.SLDASM]
2024-12-18 Remove obsolete motor and limit switch test files; update README with project overview and setup instructions
2025-06-09 Refactor delay definitions and command handling in Arduino code; update command generation in Python script
2025-06-27 Refactor delay definitions and optimize command handling in Arduino code; update serial communication in Python script
